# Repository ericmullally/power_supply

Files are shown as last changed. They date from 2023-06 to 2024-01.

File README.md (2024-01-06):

# power_supply

Simple build for a Breadboard power supply.

## Major hardware
* STM32F401 MCU.
* VIM-878-336640 LCD.
* BU91797MUF-ME2 LCd Driver.
* tps63070 Voltage regulator.

## Details 
The power supply is meant to provide voltage in the 1V - 8V DC range to a user breadboard.
It uses either a USB type B connection or a power jack connector not to exceed 16V.  The 
tps63070 is rated to supply up to 2 amps of current depending on the input and output 
voltages (see Docs->ICs for datasheet). 

## Documents 
Attached is the basic code written for the STM32Ide version 1.11 using the HAL library.
The driver for the LCD display, along with the schematics for the board (for KiCad) and relevant datasheets. 

## License
This repository is licensed under The MIT License.

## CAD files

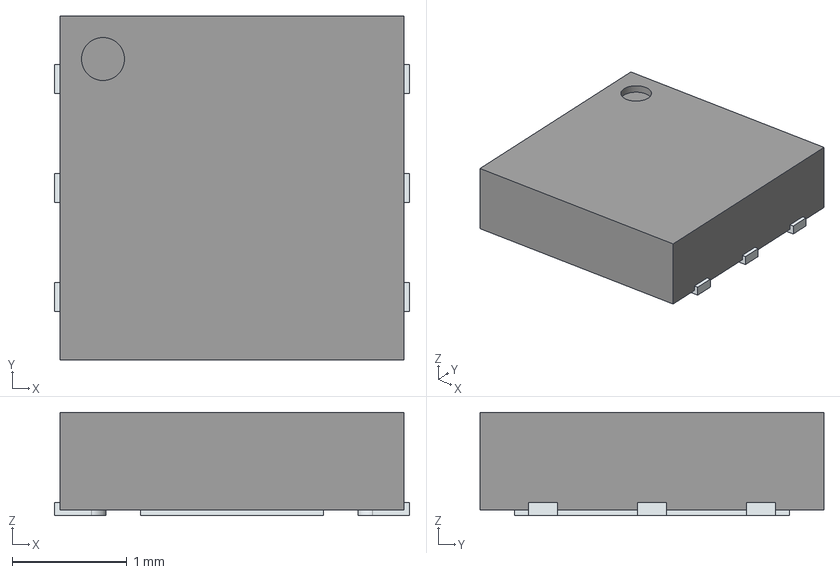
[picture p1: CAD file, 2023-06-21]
Docs/models/LDO40LPU33RY_KiCad/LDO40LPU33RY.stp
3.10 x 3.00 x 0.9 mm
ThermalPin
PinsArrayLR

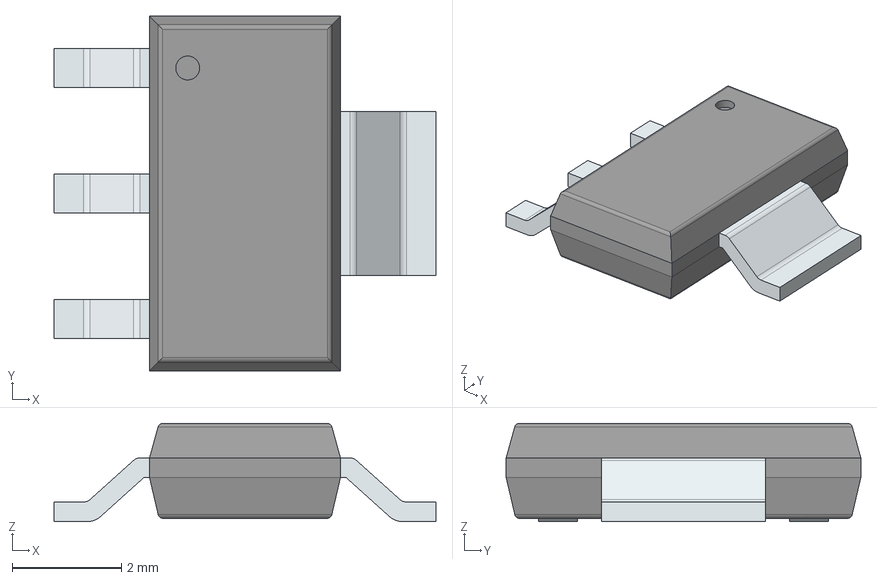
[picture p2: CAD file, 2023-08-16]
Docs/models/MCP1754ST-3302E_DB/MCP1754ST-3302E_DB.stp
7.00 x 6.50 x 1.80 mm
PinsArrayL
FilletPinR

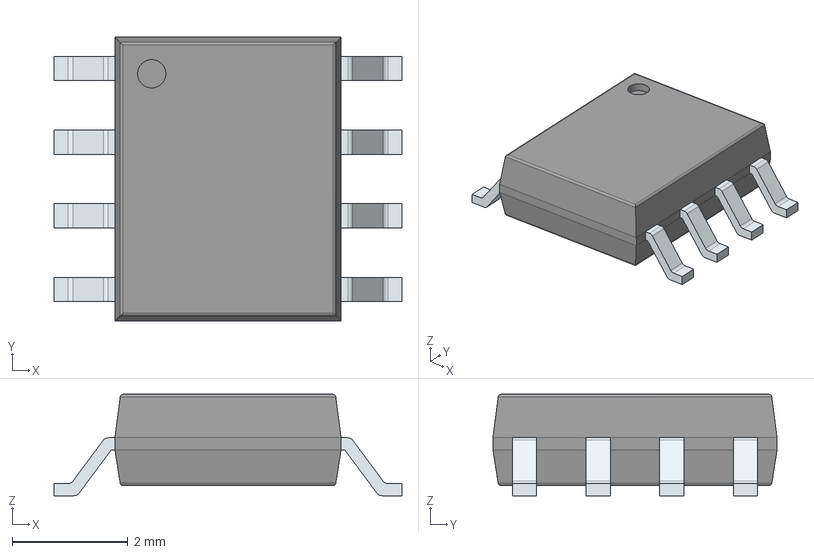
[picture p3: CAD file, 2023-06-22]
Docs/models/ISL23511WFB8Z_KiCad/ISL23511WFB8Z.stp
6.00 x 4.90 x 1.75 mm
PinsArrayLR

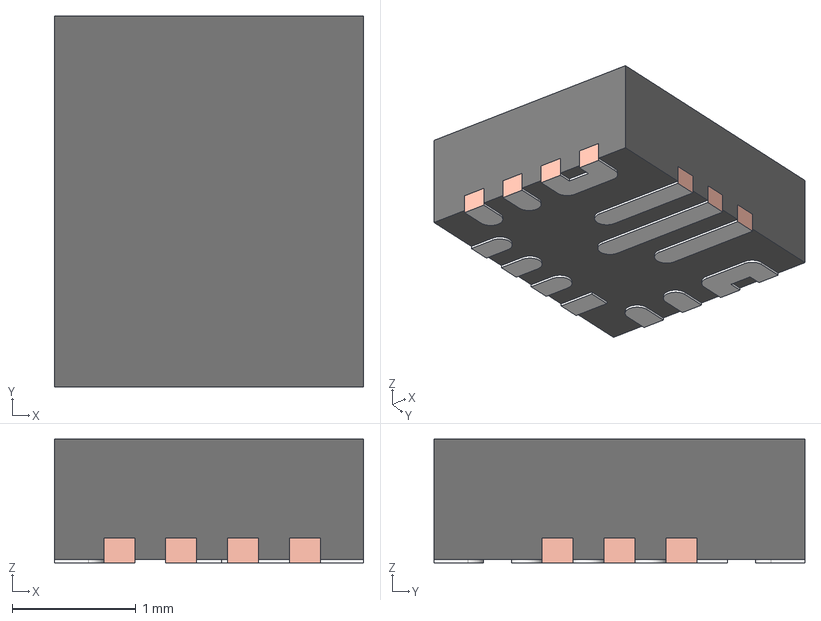
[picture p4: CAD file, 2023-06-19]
Docs/models/TPS63070RNMR/TPS63070RNMR.stp
2.50 x 3.00 x 1.00 mm
FRAME-RNM0015A
BODY-QFN
PIN1-ID

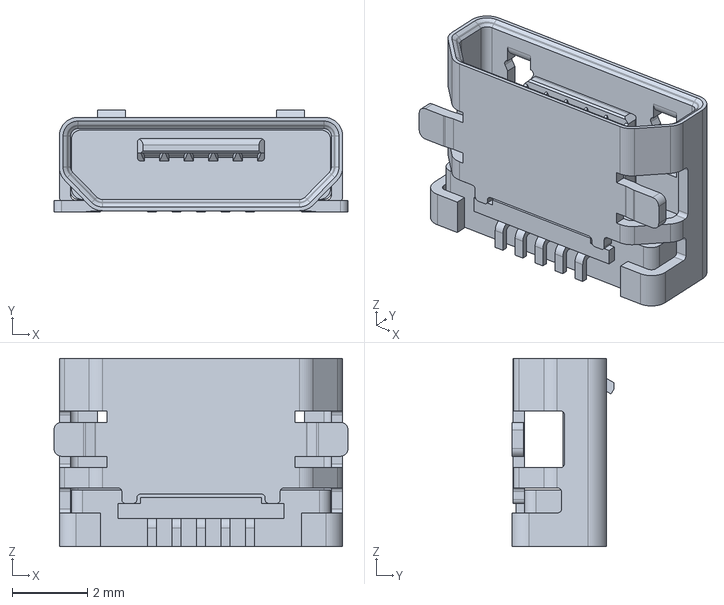
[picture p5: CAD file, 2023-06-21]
Docs/models/USB_2174507-2_KiCad/2174507-2.stp
7.80 x 2.70 x 5.00 mm

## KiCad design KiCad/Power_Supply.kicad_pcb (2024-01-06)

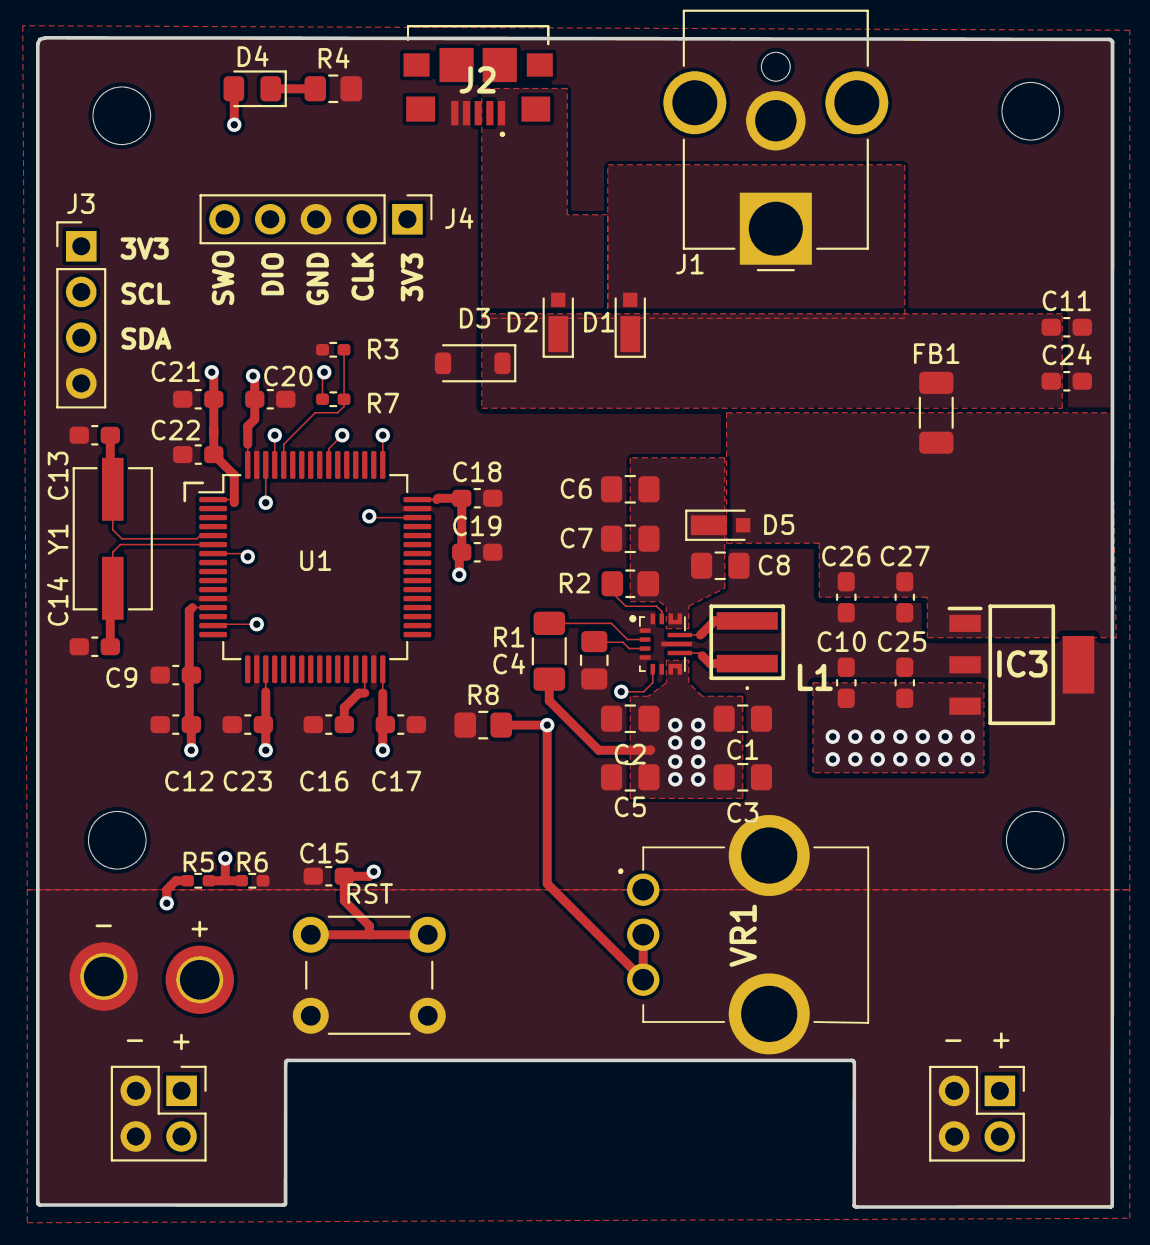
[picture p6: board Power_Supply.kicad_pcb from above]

Board: 4 copper layers, 59.7 x 65.0 mm, 60 parts (0 on the bottom side), 26 nets.

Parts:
+: BTM_OUT; PinHeader_2x02_P2.54mm_Vertical
+#2: Testing; MountingHole_2.2mm_M2_DIN965_Pad_TopOnly
-: Testing; MountingHole_2.2mm_M2_DIN965_Pad_TopOnly
C1, C2, C3: 22uF; C_0805_2012Metric_Pad1.18x1.45mm_HandSolder
C4: 100nF; C_0805_2012Metric_Pad1.18x1.45mm_HandSolder
C5, C6, C7, C8: 10uF; C_0805_2012Metric_Pad1.18x1.45mm_HandSolder
C9, C15, C17, C18, C19, C20, C21, C22: 100nF; C_0603_1608Metric_Pad1.08x0.95mm_HandSolder
C10, C11, C12, C24, C26: 1uF; C_0603_1608Metric_Pad1.08x0.95mm_HandSolder
C13, C14: 16pF; C_0603_1608Metric_Pad1.08x0.95mm_HandSolder
C16, C23: 4.7uF; C_0603_1608Metric_Pad1.08x0.95mm_HandSolder
C25, C27: .1uF; C_0603_1608Metric_Pad1.08x0.95mm_HandSolder
D1, D2, D5: D_Schottky; D_MicroSMP_AK
D3: 30V+; D_SOD-123
D4: Green_Led; LED_0805_2012Metric_Pad1.15x1.40mm_HandSolder
FB1: FerriteBead; L_1206_3216Metric_Pad1.22x1.90mm_HandSolder
H1, H2, H3, H4: MountingHole; MountingHole_3.2mm_M3
IC1: TPS63070RNMR; TPS630701RNMR
IC3: MCP1754ST-3302E_DB
J1: Jack-DC; BarrelJack_CUI_PJ-063AH_Horizontal_CircularHoles
J2: USB_B; 21745072
J3: LCD_connector; PinHeader_1x04_P2.54mm_Vertical
J4: SWD; PinHeader_1x05_P2.54mm_Vertical
J5: TOP_OUT; PinHeader_2x02_P2.54mm_Vertical
L1: XFL4020-152MEC; XFL4020152MEC
R1: 100K; R_1206_3216Metric_Pad1.30x1.75mm_HandSolder
R2: 10k; R_0805_2012Metric_Pad1.20x1.40mm_HandSolder
R3, R5, R7: 1K; R_0402_1005Metric_Pad0.72x0.64mm_HandSolder
R4: 165; R_0805_2012Metric_Pad1.20x1.40mm_HandSolder
R6: 500; R_0402_1005Metric_Pad0.72x0.64mm_HandSolder
R8: 2K; R_0805_2012Metric_Pad1.20x1.40mm_HandSolder
RST: NRST; SW_PUSH_6mm_H4.3mm
U1: STM32F401RBTx; LQFP-64_10x10mm_P0.5mm
VR1: PTV09A-1015U-B203; PTV09A1015UB203
Y1: Crystal; Crystal_SMD_ECS_CSM3X-2Pin_7.6x4.1mm

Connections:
+3.3V: C9.2, C10.1, C12.2, C17.1, C18.1, C19.1, C20.1, C21.1, C22.1, C23.1, C25.1, D4.2 (A), IC3.3 (VOUT), J3.1, J4.1, R7.1, U1.1 (VBAT), U1.13 (VREF+), U1.19 (VDD), U1.32 (VDD), U1.48 (VDD), U1.64 (VDD)
/BOOT: R3.2, R7.2, U1.60 (BOOT0)
/MCU_POWER/JACK_OUT: D1.2 (A), J1.1
/MCU_POWER/USB_OUT: D2.2 (A), J2.1 (VBUS)
/NRST: C15.2, RST.2, U1.7 (NRST)
/Output_circuitry/EN: IC1.14 (EN), R2.1
/Output_circuitry/L1: IC1.9 (L2), L1.1
/Output_circuitry/L2: IC1.11 (L1), L1.2
/Output_circuitry/PG: IC1.2 (PG), R1.2
/Output_circuitry/VIN: C6.1, C7.1, C8.1, D5.1 (K), IC1.12 (VIN_1), IC1.13 (VIN_2), IC1.16, R2.2
/Output_circuitry/Vaux: C4.2, IC1.3 (VAUX)
/VCAP: C16.2, U1.30 (VCAP1)
ADC: +.1, +.2, +#2.1, C1.1, C2.1, C3.1, C5.1, IC1.7 (VOUT_1), IC1.8 (VOUT_2), IC1.17, J5.1, J5.2, R1.1, R5.1, VR1.1 (CCW)
CW: IC1.5 (FB), R8.2, VR1.2 (WIPER), VR1.3 (CW)
GND: +.3, +.4, -.1, C1.2, C2.2, C3.2, C4.1, C5.2, C6.2, C7.2, C8.2, C9.1, C10.2, C11.2, C12.1, C13.1, C14.1, C15.1, C16.1, C17.2, C18.2, C19.2, C20.2, C21.2, C22.2, C23.2, C24.2, C25.2, C26.2, C27.2, D3.2 (A), IC1.1 (PS/S), IC1.4 (GND), IC1.6 (FB2), IC1.10 (PGND), IC1.15 (VSEL), IC3.2 (GND_1), IC3.4 (GND_2), J1.2, J2.4 (GND), J2.5 (Shield), J3.4, J4.3, J5.3, J5.4, R3.1, R4.2, R6.1, R8.1, RST.1, U1.12 (VSSA), U1.18 (VSS), U1.31 (VSS), U1.47 (VSS), U1.63 (VSS), VR1.MH1, VR1.MH2
Main_in: C26.1, C27.1, D5.2 (A), FB1.2, IC3.1 (VIN)
unnamed: C11.1, C24.1, D1.1 (K), D2.1 (K), D3.1 (K), FB1.1
unnamed: D4.1 (K), R4.1
unnamed: R5.2, R6.2, U1.15 (PA1)
unnamed: C13.2, U1.5 (PH0), Y1.2
unnamed: C14.2, U1.6 (PH1), Y1.1
SCL: J3.2, U1.61 (PB8)
SDA: J3.3, U1.62 (PB9)
SWCLK: J4.2, U1.49 (PA14)
SWDIO: J4.4, U1.46 (PA13)
SWO: J4.5, U1.55 (PB3)

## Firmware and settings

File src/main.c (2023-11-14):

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
/* Includes ------------------------------------------------------------------*/
#include "main.h"

/* USER CODE BEGIN Includes */
#include "VIM_878.h"
/* USER CODE END Includes */

/* USER CODE BEGIN PM */
const float ADC_STEP = 3.3 / 4096 ;
/* USER CODE END PM */

ADC_HandleTypeDef hadc1;

I2C_HandleTypeDef hi2c1;

void SystemClock_Config(void);
static void MX_GPIO_Init(void);
static void MX_I2C1_Init(void);
static void MX_ADC1_Init(void);
/* USER CODE BEGIN PFP */
void BCD_calculation(int num);
void write_to_lcd(int raw_reading);
int convert_adc_reading(uint32_t raw);
/* USER CODE END PFP */

/* USER CODE BEGIN 0 */
int reading[4];
uint32_t prev_raw_adc = 0;
/* USER CODE END 0 */

/**
  * @brief  The application entry point.
  * @retval int
  */
int main(void)
{
  /* MCU Configuration--------------------------------------------------------*/

  /* Reset of all peripherals, Initializes the Flash interface and the Systick. */
  HAL_Init();

  /* Configure the system clock */
  SystemClock_Config();

  /* Initialize all configured peripherals */
  MX_GPIO_Init();
  MX_I2C1_Init();
  MX_ADC1_Init();
  /* USER CODE BEGIN 2 */


  lcd_init(hi2c1);
  HAL_Delay(500);
  write_to_lcd(4567);

  /* USER CODE END 2 */

  /* Infinite loop */
  /* USER CODE BEGIN WHILE */
  while (1)
  {
    /* USER CODE END WHILE */
	HAL_ADC_Start(&hadc1);

	if(HAL_ADC_PollForConversion(&hadc1, 100000) == HAL_OK){
		uint32_t temp  = HAL_ADC_GetValue(&hadc1);

		if(temp > (prev_raw_adc + 20) || temp < (prev_raw_adc - 20) ){
			prev_raw_adc = temp;
			int new_reading = convert_adc_reading(temp);
			write_to_lcd(new_reading);
		}

		HAL_ADC_Stop(&hadc1);
	}

    HAL_Delay(500);

	/* USER CODE BEGIN 3 */
  }
  /* USER CODE END 3 */
}

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
/* USER CODE BEGIN 4 */


/*
 * @breif takes a unint32_t number and extracts the value of each place in the number,
 * to the reading variable plca representations.
 *
 * @example if passed "123" the reading variable would be {0,1,2,3}
 *
 * */
void BCD_calculation(int num){

	   int bcdResult = 0;
	   int shift = 0;

	   // Mask for extraction.
	   uint8_t Mask = 0xF;

	   while (num > 0) {
		   // Get the ones place shift it onto the result by 4 bits each time.
		   // this method requires no checking for add 3 if > 9.
	      bcdResult |= (num % 10) << (shift++ << 2);
	      num /= 10;
	   }

	   // Shift the result in the opposite diretion and extract the number.
	   reading[3] = bcdResult & Mask;
	   reading[2] = (bcdResult >> 4) & Mask;
	   reading[1] = (bcdResult >> 8) & Mask;
	   reading[0] = (bcdResult >> 12) & Mask;
}

/*
 * @brief decides how many numbers are needed and write to the lcd.
 * @params Raw data from the current adc reading.
 * */
void write_to_lcd(int raw_reading){

	  BCD_calculation(raw_reading);
	  if((reading[0]) == 0){

		  int reading_cpy[3] = {reading[1], reading[2], reading[3]}; // taking off the thousands place

		  burst_write(hi2c1, 4, 5, reading_cpy);
	  }else{
		  burst_write(hi2c1, 3, 6, reading);
	  }

}

/*
 * @brief calculates the voltage value and takes away the decimal for bcd conversion.
 *
 * @params Raw data from the current adc reading.
 * @returns ADC Reading integer representaion.
 * */
int convert_adc_reading(uint32_t raw){

	int converted = (int)(((ADC_STEP * raw) * 3.2) * 100);
	return converted;
}

/* USER CODE END 4 */
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


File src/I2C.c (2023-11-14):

/*
 * I2C.h
 *
 *  Created on: Oct 25, 2023
 *      Author: eric
 */


#include "I2C.h"

// CR1 Registers
#define I2C_PE_BIT_POS 			0
#define I2C_SMBUS_BIT_POS		1
#define I2C_SMBTYPE_BIT_POS		3
#define I2C_ENARP_BIT_POS		4
#define I2C_ENPEC_BIT_POS		5
#define I2C_ENGC_BIT_POS		6
#define I2C_NOSTRETCH_BIT_POS 	7
#define I2C_START_BIT_POS		8
#define I2C_STOP_BIT_POS		9
#define I2C_ACK_BIT_POS			10
#define I2C_POS_BIT_POS			11
#define I2C_PEC_BIT_POS			12
#define I2C_ALERT_BIT_POS		13
#define I2C_SWRST_BIT_POS		15

// CR2 Registers
#define I2C_FREQ_BIT_POS		0
#define I2C_ITRREN_BIT_POS		8
#define I2C_ITEVTEN_BIT_POS		9
#define I2C_ITBUFEN_BIT_POS		10
#define I2C_DMAEN_BIT_POS		11

// OAR1 Registers
#define I2C_ADD0_BIT_POS		0
#define I2C_ADD7_BIT_POS		1
#define I2C_ADDMODE_BIT_POS		15

// Status Register 1
#define I2C_SB_BIT_POS			0
#define I2C_ADDR_BIT_POS		1
#define I2C_BTF_BIT_POS			2
#define I2C_ADD10_BIT_POS		3
#define I2C_STOPF_BIT_POS		4
#define I2C_RXNE_BIT_POS		6
#define I2C_TXE_BIT_POS			7
#define I2C_BERR_BIT_POS		8
#define I2C_ARLO_BIT_POS		9
#define I2C_AF_BIT_POS			10
#define I2C_OVR_BIT_POS			11
#define I2C_PECERR_BIT_POS		12
#define I2C_TIMEOUT_BIT_POS		14
#define I2C_SMBALERT_BIT_POS	15

// Status register 2
#define I2C_BUSY_BIT_POS		1

// Clock control register
#define I2C_CCR_BIT_POS			0
#define I2C_CCR_DUTY_BIT_POS	14
#define I2C_CCR_FS_BIT_POS		15

int SDA_PIN;
int SCL_PIN;

// Clock enable
#define I2C1_PCLCK_EN()			(RCC->APB1ENR |= (1UL << 21))
#define I2C2_PCLCK_EN()			(RCC->APB1ENR |= (1UL << 22))

// Private functions
uint32_t Get_APB1_ClockSpeed();
void Gen_Start_condition(I2C_TypeDef * tI2Cx);
void Gen_Stop_condition(I2C_TypeDef * tI2Cx);

// Function definitions
void I2C_Gpio_Init(I2C_Instance_T * pI2Cx){

	// Enable Port B clock
	RCC->AHB1ENR |= (1UL << 2);

	if(pI2Cx->I2Cx == I2C1){
		if(pI2Cx->config.Pin_Choice_default == I2C1_ALT_PINS){
			// Pins are PB8-9
			SCL_PIN = 8;
			SDA_PIN = 9;

			// Set Pin mode to Alternate function
			GPIOB->MODER &= ~((3UL << 16) |  (3UL << 18));
			GPIOB->MODER |=  ((2UL << 16) |  (2UL << 18));

			// Set the alternate function to AF04
			GPIOB->AFR[1] &= ~((15UL << 0)|(15UL << 4));
			GPIOB->AFR[1] |=  ((4UL << 0)|(4UL << 4));

			// Set open Drain
			GPIOB->OTYPER |= ((1UL << 8)| (1UL << 9));

			// Set internal pull up
			GPIOB->PUPDR &= ~((3UL << 16) |  (3UL << 18));
			GPIOB->PUPDR |=  ((1UL << 16) |  (1UL << 18));

		}else{
			// Pins are PB6-7
			SCL_PIN = 6;
			SDA_PIN = 7;
			// Set Pin mode to Alternate function
			GPIOB->MODER &= ~((3UL << 12) |  (3UL << 14));
			GPIOB->MODER |=  ((2UL << 12) |  (2UL << 14));

			// Set the alternate function to AF04
			GPIOB->AFR[0] &= ~((15UL << 28)|(15UL << 24));
			GPIOB->AFR[0] |=  ((4UL << 28)|(4UL << 24));

			// Set open Drain
			GPIOB->OTYPER |= ((1UL << 7)| (1UL << 6));

			// Set internal pull up
			GPIOB->PUPDR &= ~((3UL << 12) |  (3UL << 14));
			GPIOB->PUPDR |=  ((1UL << 12) |  (1UL << 14));
		}
	}else if(pI2Cx->I2Cx == I2C2){
		// Pins are PB10-11
		SCL_PIN = 10;
		SDA_PIN = 11;
		// Set Pin mode to Alternate function
		GPIOB->MODER &= ~((3UL << 20) |  (3UL << 22));
		GPIOB->MODER |=  ((2UL << 20) |  (2UL << 22));

		// Set the alternate function to AF04
		GPIOB->AFR[1] &= ~((15UL << 8)|(15UL << 12));
		GPIOB->AFR[1] |=  ((4UL << 8)|(4UL << 12));

		// Set open Drain
		GPIOB->OTYPER |= ((1UL << 11)| (1UL << 10));

		// Set internal pull up
		GPIOB->PUPDR &= ~((3UL << 20) |  (3UL << 22));
		GPIOB->PUPDR |=  ((1UL << 20) |  (1UL << 22));
	}



}

void I2C_Init(I2C_Instance_T * pI2Cx){
	I2C_Gpio_Init(pI2Cx);

	uint32_t APB1_Clock_Speed = Get_APB1_ClockSpeed();

	if(APB1_Clock_Speed == 0){
		printf("Clock Speed must be > 2MHz");
		return;
	}
	// TODO Implement FM mode calculations
	float T_PCLK1 = (1 / APB1_Clock_Speed) * 1000000000; // period in NANO seconds
	uint32_t T_Low = 5000;
	uint32_t Max_Rise_T = 1000;

	if(pI2Cx->I2Cx == I2C1){

		// Enable the clock
		I2C1_PCLCK_EN();

		// Make sure I2C is disabled
		I2C1->CR1 &= ~(1UL << I2C_PE_BIT_POS);
		// Give the peripheral clock Frequency
		I2C1->CR2 |= ((APB1_Clock_Speed / 1000000) << I2C_FREQ_BIT_POS);
		// Calculate the Clock control register
		I2C1->CCR |= ( ((int)(T_Low / T_PCLK1)) << I2C_CCR_BIT_POS);
		// Calculate the rise time based on Max SCL Rise time in SM mode 1000 / T_PCLCK1
		I2C1->TRISE |= ((int)((Max_Rise_T / T_PCLK1) +1) << 0);

		// Enable the I2C Peripheral
		I2C1->CR1 |= (1UL << I2C_PE_BIT_POS);

	}else if(pI2Cx->I2Cx == I2C2){

		I2C2_PCLCK_EN();
		// Make sure I2C is disabled
		I2C2->CR1 &= ~(1UL << I2C_PE_BIT_POS);
		// Give the peripheral clock Frequency
		I2C2->CR2 |= ((APB1_Clock_Speed / 1000000) << I2C_FREQ_BIT_POS);
		// Calculate the Clock control register
		I2C2->CCR |= ( ((int)(T_Low / T_PCLK1)) << I2C_CCR_BIT_POS);
		// Calculate the rise time based on Max SCL Rise time in SM mode 1000 / T_PCLCK1
		I2C2->TRISE |= ((int)((Max_Rise_T / T_PCLK1) +1) << 0);

		// Enable the I2C Peripheral
		I2C2->CR1 |= (1UL << I2C_PE_BIT_POS);
	}




}

uint32_t Get_APB1_ClockSpeed(){

	uint8_t APB_Clck_divisions[5] = {1, 2, 4, 8, 16};
	uint16_t AHB_Clck_divisions[9] = {1, 2, 4, 8, 16, 64, 128, 256, 512};
	uint32_t APB1_Freq = 0;

	uint32_t SYS_clock_SRC  = RCC->CFGR & (3UL << 2);
	uint32_t APB1_Presacaler = RCC->CFGR & (7UL << 10);
	uint32_t AHB_Presacaler = RCC->CFGR & (15UL << 4);
	uint32_t HSI_Freq = 16000000;
	uint32_t HSE_Freq = 25000000;


	switch (SYS_clock_SRC){

	case 0:
		// HSI
		if(AHB_Presacaler < 4){
			if(APB1_Presacaler  == 0){
				APB1_Freq =  HSI_Freq / APB_Clck_divisions[APB1_Presacaler];
			}else{
				APB1_Freq =  HSI_Freq / APB_Clck_divisions[APB1_Presacaler -3];
			}

		}else{
			if(APB1_Presacaler  == 0){
				APB1_Freq =  (HSI_Freq / AHB_Clck_divisions[AHB_Presacaler - 7]) / APB_Clck_divisions[APB1_Presacaler];
			}else{
				APB1_Freq =  (HSI_Freq / AHB_Clck_divisions[AHB_Presacaler - 7]) / APB_Clck_divisions[APB1_Presacaler -3];
			}
		}

	case 1:
		// HSE
		if(AHB_Presacaler < 4){
			if(APB1_Presacaler  == 0){
				APB1_Freq =  HSE_Freq / APB_Clck_divisions[APB1_Presacaler];
			}else{
				APB1_Freq =  HSE_Freq / APB_Clck_divisions[APB1_Presacaler -3];
			}

		}else{
			if(APB1_Presacaler  == 0){
				APB1_Freq =  (HSE_Freq / AHB_Clck_divisions[AHB_Presacaler - 7]) / APB_Clck_divisions[APB1_Presacaler];
			}else{
				APB1_Freq =  (HSE_Freq / AHB_Clck_divisions[AHB_Presacaler - 7]) / APB_Clck_divisions[APB1_Presacaler -3];
			}
		}

	case 2:
		// TODO Calculations for PLL clock.
		// PLL


	};
	if(APB1_Freq < 2000000){
		return 0;
	}else{
		return APB1_Freq;
	}



}
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

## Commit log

2023-03-20 changed voltage rgeulators
    [NCL37733 SPREADSHEET DESIGN TOOL.XLSX]
2023-03-20 Schematics added
    [NCL37733 SPREADSHEET DESIGN TOOL.XLSX, power_supply.kicad_pcb, power_supply.kicad_sch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]
2023-03-22 added power schematic to design
    [LCD.kicad_sch, VDD.kicad_sch, power_supply.kicad_sch]
2023-03-22 Adjusted the VDD supply schematic
    [LCD.kicad_sch, VDD.kicad_sch, power_supply.kicad_pcb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]
2023-03-22 Added I2C modules
    [LCD.kicad_sch, VDD.kicad_sch, power_supply.kicad_pcb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]
2023-03-25 Lcd files started.
    [LCD.kicad_sch]
2023-03-29 Ki cad schematic update.
    [LCD.kicad_sch, Main_Supply.kicad_sch, power_supply.kicad_sch]
2023-04-08 Schematics updated. footprint assignment and layout still needed
    [Board_PWR.kicad_sch, Main_Supply.kicad_sch, Main_output.kicad_sch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]
2023-05-16 Updated Schematic and VIM878
    [Board_PWR.kicad_sch, LCD.kicad_sch, Main_Supply.kicad_sch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]
2023-05-25 Kicad model updated.
    [Board_PWR.kicad_sch, LCD.kicad_sch, VDD.kicad_sch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]
2023-06-05 Updated schematics. and added the correct Driver files for stm32f401
    [power_supply-B_Cu.gbr, power_supply-B_Mask.gbr, power_supply-B_Paste.gbr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]
2023-06-19 Re-design of board started.
    [AP7370-33WW-7.stp, Board_PWR.kicad_sch, LCD.kicad_sch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]
2023-06-21 Schematic redesign needs two footprints before complete.
    [2174507-2.stp, AP7370-33WW-7.stp, LDO40LPU33RY.stp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]
2023-06-22 Board layout preleminary complete.
    [ISL23511WFB8Z.stp, MCU_POWER.kicad_sch, Output_circuitry.kicad_sch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]
2023-06-22 Boot-0 and button layout updated.
    [Power_Supply.kicad_pcb, Power_Supply.kicad_sch]
2023-06-23 Added some notes and extra ground vias.
    [MCU_POWER.kicad_sch, Output_circuitry.kicad_sch, Power_Supply.kicad_pcb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]
2023-08-02 Starting revision 1.1
    [MCU_POWER.kicad_sch, Output_circuitry.kicad_sch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]
2023-08-16 pushing ofr system reset
    [MCP1754ST-3302E_DB.stp, MCU_POWER.kicad_sch, Output_circuitry.kicad_sch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]
2023-10-04 Replaced pot.
    [MCU_POWER.kicad_sch, Output_circuitry.kicad_sch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]
2024-01-06 Removed unused LCD Docs
    [Power_Supply.kicad_pcb]

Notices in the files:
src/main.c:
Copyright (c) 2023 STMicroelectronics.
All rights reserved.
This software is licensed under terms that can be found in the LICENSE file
